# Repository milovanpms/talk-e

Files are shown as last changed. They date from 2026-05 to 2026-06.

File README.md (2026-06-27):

<p align="center">
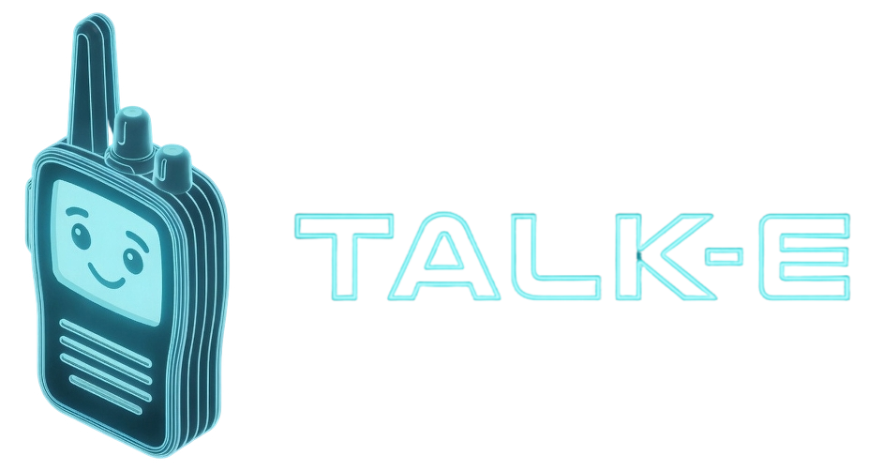
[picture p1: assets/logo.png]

</p>

<h1 align="center"></h1>

<h3 align="center">Talk-E is a walkie-talkie powered by LoRa and an ESP32-S3, operating on the 433 MHz band. And it mostly works.</h3>

<p align="center">
  
  
  
  
  
  
</p>

<h5 align="center"><a href="https://milovan.me">milovan.me</a></h5>

## In a nutshell
- **What** : Two identical devices, one button to talk, and that's it.
- **Why** : We didn't have much time, so we wanted something original, interactive, and fun to demo. The kind of project you understand immediately just by holding it in your hands.
- **Context** : Radiocommunication student project, two-person team.

## Documentation

The documentation is quite detailed, so each part has its own page instead of having it all here.

### Find your happiness:
- ⚙️ [Hardware Architecture](./docs/architecture.md): Functional synoptic diagram and component details
- 🛠️ [Firmware](./docs/firmware.md): ESP-IDF, libraries, code architecture
- 📡 [Radio Parameters](./docs/radio.md): How we use LoRa
- 🎙️ [Audio Processing](./docs/audio.md): A voice's journey through the system
- 👤 [Human-Machine Interface](./docs/hmi.md): How does it works for the user
- 🔋 [Power Supply Circuit](./docs/power.md): Power management and energy consumption
- 🔌 [Electronics](./docs/electronics.md): Prototyping, KiCad, RF design, routing rules, our conception choices
- 📐 [Mechanical Design](./docs/cad.md): Our vision of an enclosure for this device

## Repository Structure 
```
├── hardware/        # KiCad schematics, PCB
├── firmware/        # ESP-IDF code
├── docs/            # Documentation, conception notes
├── assets/          # Images, schematics and illustrations
└── case/            # 3D models
```

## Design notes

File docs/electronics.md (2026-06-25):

# 🔌 Electronics

## Prototyping

Before diving headfirst into a custom PCB, we did what every engineer on the planet would do: we grabbed a dev board off the shelf and started tinkering with it. The goal was to validate the core ideas: LoRa audio streaming, Opus encoding on an **ESP32** and the FreeRTOS task architecture.

### The development platform

The [**TTGO T-Beam V1.1**](https://github.com/lilygo/ttgo-t-beam) (by LilyGO) was our prototyping board of choice. It's a compact development board built around the original **ESP32**, featuring an **SX1276** LoRa transceiver, buttons, and a built-in **Li-Ion charging circuit** with a 18650 battery holder (even though we won't use the charging circuit).



The T-Beam already bundles almost everything the project requires on a single board: an ESP32 and a LoRa radio. This let us focus entirely on firmware during the prototyping phase without wiring up the LoRa module on our breadboard.

### What the prototyping phase validated

By the time the PCB was designed, the following had been confirmed working on the T-Beam:

- Opus encode/decode pipeline at `8 kHz`, `10 kbps`, over I2S and ADC
* LoRa TX/RX at SF7, BW 250 kHz, CR 4/5 on 433 MHz
- FreeRTOS task architecture (five concurrent tasks, dual-core assignment)
* Audio RX queue and jitter buffer
- SH1106 OLED via I2C with U8G2
* EC12 quadrature encoder decoding and PTT debouncing
- Vibration motor + FreeRTOS timer for haptic pulses
* TX/RX status LEDs

Essentially, the firmware was feature-complete before the PCB was shipped. The transition from T-Beam to custom board was mostly a matter of re-mapping GPIOs.

---

## PCB Design

With the firmware validated on the T-Beam, the next step was to translate everything into a custom PCB. The constraints were clear: fit the complete circuit onto a board small enough to live inside a handheld enclosure, while keeping the design manufacturable by a standard two-layer process and easy to solder, even with our clumsy hands.

The PCB was designed in **KiCad 10.0** and fabricated by **JLCPCB**.

> [!NOTE]
> As of writing, the PCB has not yet been soldered. Any assembly-related issues will be documented here once the board is populated and tested.

### Board overview
 
| Parameter | Value |
|---|---|
| Dimensions | `51.145 mm × 95 mm` |
| Layers | 2 (`F.Cu` + `B.Cu`) |
| Substrate | FR4 |
| Board thickness | `1.6 mm` |
| Copper thickness | `35 µm` |
| Ground planes | Both layers (poured) |
| Mounting holes | 2x M3 |

The board is rectangular and sized to fit inside a handheld enclosure with margin for mounting hardware. Two M3 mounting holes are placed at the corners.

<p align="center">
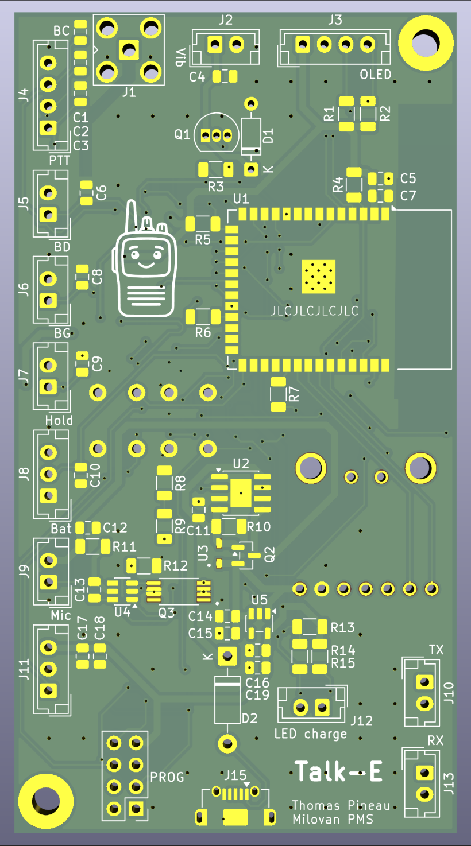
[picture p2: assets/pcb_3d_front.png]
  
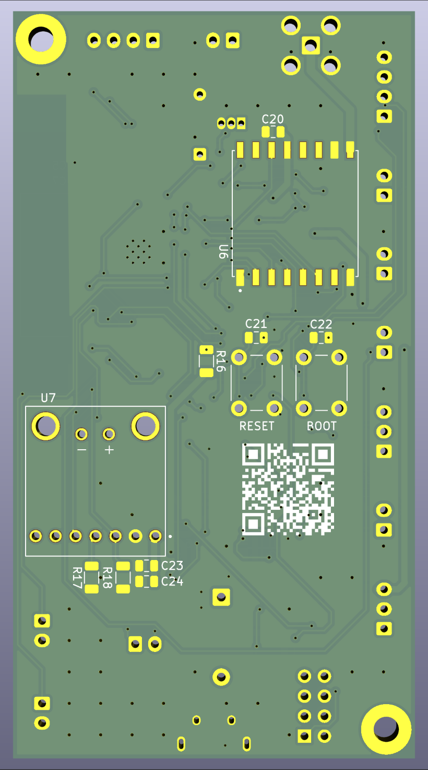
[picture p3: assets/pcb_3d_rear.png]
  
</p>

### Schematic structure

The schematic is split into two separate sheets:
 
**Sheet 1 - Power (`ihm.kicad_sch`):** Contains the complete power supply chain: Li-Ion charging (**TP4056**), battery protection (**DW01A + FS8205A**), voltage regulation (**AP2112K-3.3**), the Micro USB input connector, the SMA RF connector, the UART programming header, the BOOT and RESET buttons, and the hardware lock switch (`SW_LOCK`).
 
**Sheet 2 - Main (`talk-e.kicad_sch`):** Contains the MCU (**ESP32-S3-WROOM-1**), LoRa module (**RFM96W** based on SX1278), audio amplifier module (**MAX98357A**), microphone (**MAX4466**), rotary encoder, PTT and side buttons, OLED display, LEDs, and vibration motor, along with all their supporting passives.

<p align="center">
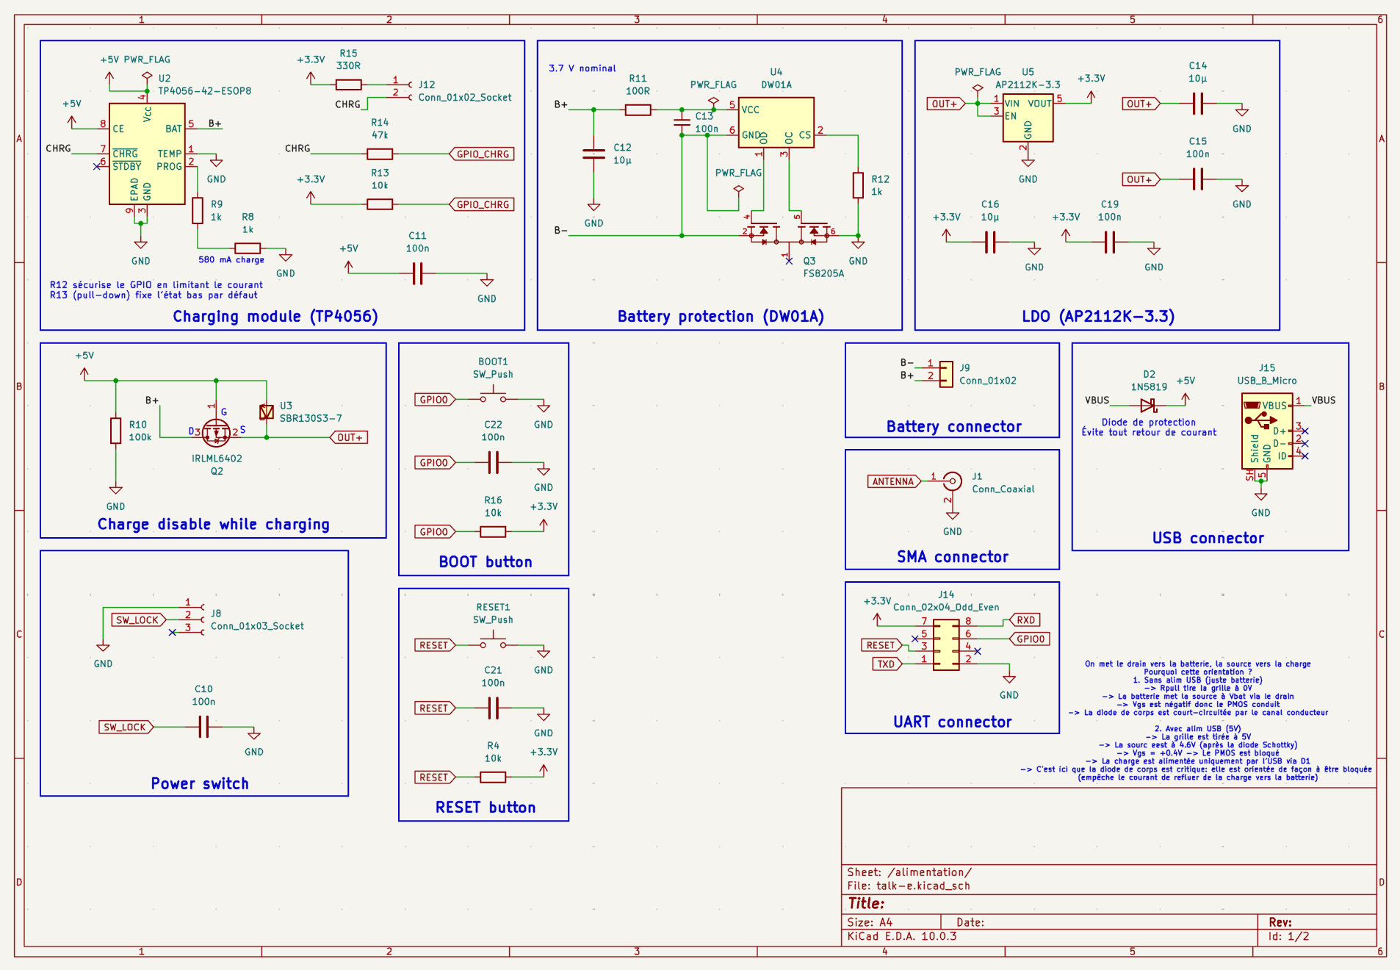
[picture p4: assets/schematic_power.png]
  
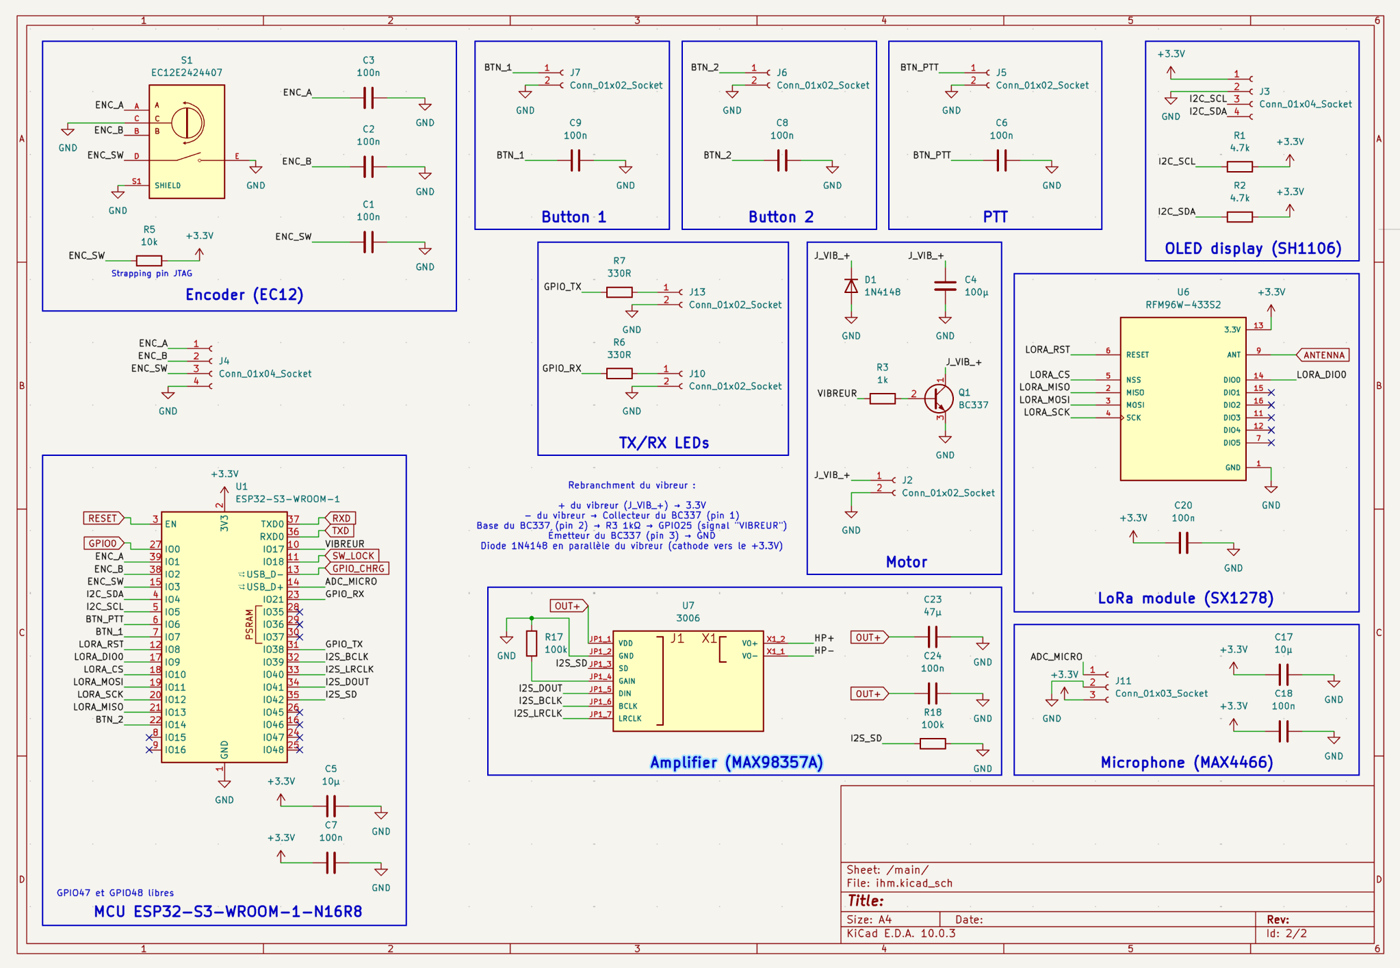
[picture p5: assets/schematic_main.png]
  
</p>

> [!NOTE]
> Yes, I know, the filenames are strange, I will update them someday.
 
Global labels tie the two sheets together for power rails (`OUT+`, `+3.3V`) and shared signals (`RESET`, `GPIO0`, `SW_LOCK`, `GPIO_CHRG`, `ANTENNA`, `RXD`, `TXD`).

### Trace widths
 
Three trace width classes are used across the board:
 
| Class | Width (mm) | Width (mil) | Used for |
|---|---|---|---|
| Power | `0.8 mm` | `31.5 mil` | All power rails (`+3.3V`, `OUT+`, `GND`, `B+`) |
| RF (microstrip) | `1.08 mm` | `42.52 mil` | SMA to SX1278 RF path |
| Signal | `0.2 mm` | `7.87 mil` | All logic signals (SPI, I2C, I2S, GPIOs) |

### RF design
 
This is probably the most layout-sensitive part of the board.
 
The **ESP32-S3-WROOM-1** module has an integrated PCB antenna, but we don't use it for LoRa. The module's antenna is only relevant if you use the ESP32's built-in Wi-Fi or Bluetooth. For LoRa, the RF signal goes through a dedicated external path.
 
The RF chain runs as follows: 

```
SMA connector (J1, Amphenol 901-143 horizontal) ➜ 50 Ω microstrip ➜ RFM96W / SX1278 (U6).
```
 
The 50 Ω microstrip was calculated using **KiCad’s built-in transmission line calculator**, using the actual stackup parameters defined in the PCB file: `1.51 mm` FR4 core with εr = `4.5`, `35 µm` copper. This yields a trace width of `1.08 mm` to match a `50 Ω` characteristic impedance.

Two ground keepout zones are placed to protect signal integrity:

- Around the microstrip trace, to exclude the ground plane and maintain the controlled impedance
* Around the **ESP32-S3** module's integrated PCB antenna, to prevent the adjacent copper from detuning it

> [!NOTE]
> Even though it is not in active use, Espressif still recommends placing a keepout zone around the integrated antenna (see [**ESP32-S3-WROOM-1** datasheet](https://documentation.espressif.com/esp32-s3-wroom-1_wroom-1u_datasheet_en.pdf)).

> ### What is a microstrip?
> A microstrip is a type of transmission line commonly used on PCBs for RF signals. It consists of a signal trace on the surface of the board, separated from the ground plane beneath it by the PCB substrate. The characteristic impedance depends on the trace width, the substrate thickness, and its dielectric constant (`εr`). Matching this impedance to `50 Ω` (the standard for RF systems) minimises reflections and ensures maximum power transfer between the SMA connector and the radio module.

### Ground planes and via stitching

Both copper layers carry a full ground pour, tied together by a dense array of vias. This was done automatically using the [**viastitching**](https://github.com/weirdgyn/viastitching) KiCad plugin, which distributes stitching vias across the board in a regular pattern.

Via stitching serves two purposes here: it lowers the ground impedance across the board (useful for the audio and power sections), and it improves RF shielding continuity around the LoRa antenna path.

### Module connectors
 
All external modules connect to the PCB via **JST EH series connectors** (2.50 mm pitch), chosen for their polarised, locking contacts — no risk of plugging something in backwards or having it vibrate loose.
 
| Connector | Pins | Module |
|---|---|---|
| `J6` | 2 | Right button |
| `J7` | 2 | Left button |
| `J9` | 2 | Battery |
| `J10` | 2 | TX LED |
| `J12` | 2 | CHRG LED |
| `J13` | 2 | RX LED |
| `J5` | 2 | PTT |
| `J2` | 2 | Vibration motor |
| `J8` | 3 | Lock switch |
| `J11` | 3 | Microphone (MAX4466) |
| `J3` | 4 | OLED display |
| `J4` | 4 | Encoder |

The **MAX98357A audio amplifier** (Adafruit breakout module, footprint `3006`) is an exception: it is soldered directly onto the PCB footprint rather than via a detachable connector, as it doesn't need a periodic replacement or disconnection.

### Power input

The board charges via **Micro USB** (`J15`, Molex 47590-0001). The USB connector feeds `VBUS` into the **TP4056** charge controller. No USB data lines are used; the connector is power-only.

A separate **UART programming header** (`PROG`, 2×4 pin header) exposes `TXD`, `RXD`, `GPIO0`, and `RESET` for flashing via a USB-to-UART adapter. The onboard `BOOT` and `RESET` push buttons allow entering the ESP32 bootloader.

### Some pictures of the board

<p align="center">
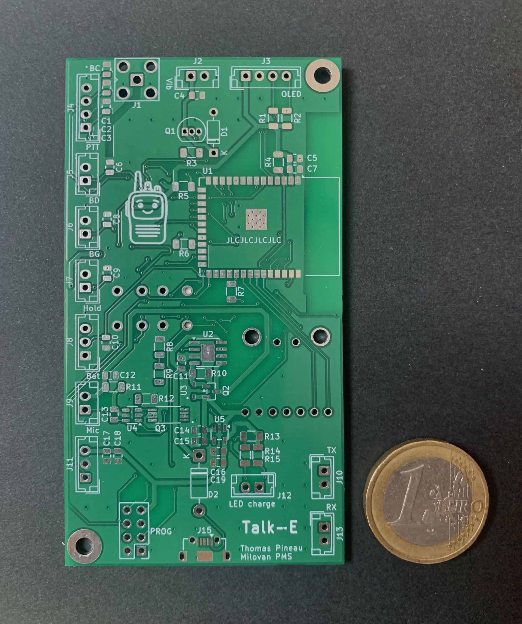
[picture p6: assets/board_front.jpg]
  
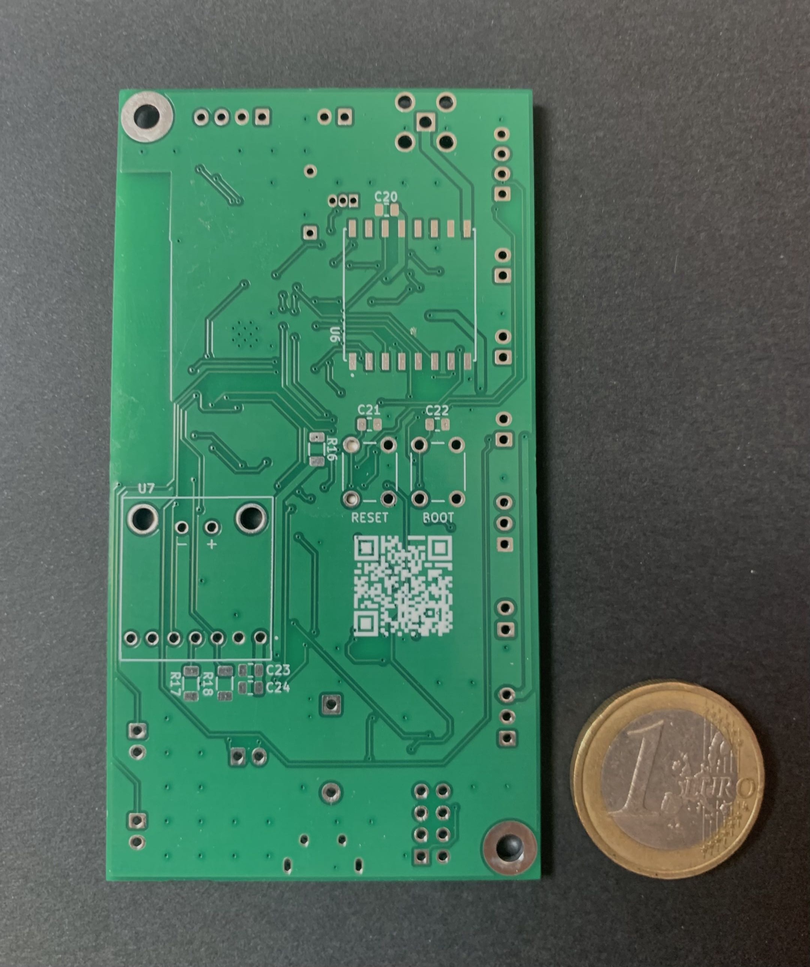
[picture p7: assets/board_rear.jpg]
  
</p>

---

## Next steps

- Assemble boards
- Validate RF performance and audio quality
- Measure real-world power consumption and autonomy

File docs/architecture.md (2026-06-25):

# ⚙️ Hardware Architecture

## Overview
The architecture is built around an **ESP32-S3** (**ESP32-S3-WROOM-1-N16R8**) that handles everything: radio via SPI, 
display via I2C, audio via I2S and GPIOs for buttons and feedback.

### Why specifically the S3?
We picked an **S3** module for its built-in PSRAM, which we needed for audio buffering. See the corresponding section on audio processing.

### Why did you choose the module with the integrated antenna?
We took the **ESP32-S3-WROOM-1** (integrated PCB antenna) instead of the **ESP32-S3-WROOM-1U**, even though we don't need the built-in `2.4 GHz` antenna. The main reason was that we already had several **ESP32-S3-WROOM-1** modules available on campus; but it would also work with the module without an antenna!

## Functional block diagram
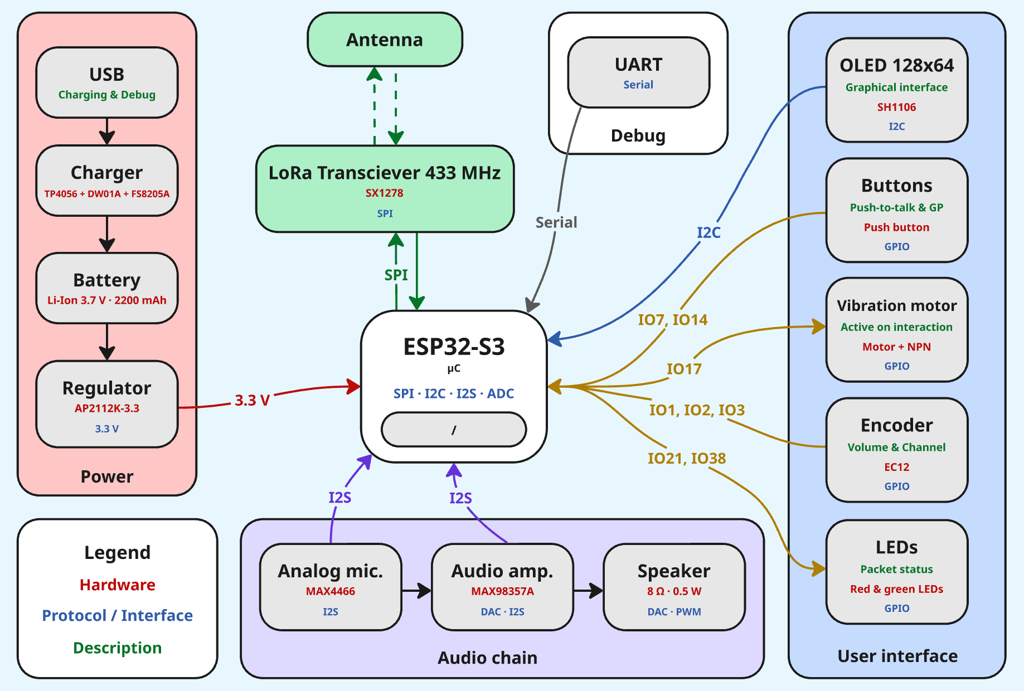
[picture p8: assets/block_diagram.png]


## Component Details

| Block | Component | Role |
|---|---|---|
| Microcontroller | **ESP32-S3** | Main processing, SPI/I2C/I2S |
| Radio | **SX1278** | LoRa transceiver, `433 MHz` |
| Audio input | **MAX4466** | Analog microphone |
| Audio output | **MAX98357A** | Class D amplifier |
| Display | **SH1106 OLED 128x64** | Status display |
| Battery | **Li-Ion 3.7V 2000mAh** | Power source |
| Charging | **TP4056** | Charge controller |
| Protection | **DW01A + FS8205A** | Overvoltage, overdischarge, short-circuit |
| Regulation | **AP2112K-3.3** | `3.3 V` |
| Vibration | Vibration motor | Haptic feedback |

## Pin Mapping

As you can see, the GPIOs are nearly fully used!

| Component | Pin | ESP32-S3 GPIO | Interface |
|---|---|---|---|
| **SX1278** | `MOSI` | `GPIO11` | SPI |
| **SX1278** | `MISO` | `GPIO13` | SPI |
| **SX1278** | `CS` | `GPIO10` | SPI |
| **SX1278** | `DIO0` | `GPIO9` | SPI |
| **SX1278** | `RST` | `GPIO8` | SPI |
| **SX1278** | `SCK` | `GPIO12` | SPI |
| **SH1106** | `SDA` | `GPIO4` | I2C |
| **SH1106** | `SCL` | `GPIO5` | I2C |
| **MAX98357A** | `BCLK` | `GPIO39` | I2S |
| **MAX98357A** | `LRCLK` | `GPIO40` | I2S |
| **MAX98357A** | `DOUT` | `GPIO41` | I2S |
| **MAX98357A** | `SD` | `GPIO42` | I2S |
| **MAX4466** | - | `GPIO14` | ADC |
| **Encoder** | `A` | `GPIO1` | GPIO |
| **Encoder** | `B` | `GPIO2` | GPIO |
| **Encoder** | `SW` | `GPIO3` | GPIO |
| **PTT button**  | - | `GPIO6` | GPIO |
| **Button 1** | - | `GPIO7` | GPIO |
| **Button 2** | - | `GPIO14` | GPIO |
| **Vibration motor** | - | `GPIO17` | GPIO |
| **Lock switch** | - | `GPIO18` | GPIO |
| **TX LED** | - | `GPIO38` | GPIO |
| **RX LED** | - | `GPIO21` | GPIO |
| **CHRG LED** | - | `GPIO13` | GPIO |
| **RESET button**| `EN` | - | GPIO |
| **BOOT button** | - | `GPIO0` | GPIO |

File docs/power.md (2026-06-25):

# 🔋 Power Supply Circuit

Designing a power supply circuit is a crucial step when you create a device. Especially portable ones: you have to think about the global consumption of the device, which battery suits the best for a *not-ridiculous* autonomy, how to charge it and how to protect the circuit; **to make sound, not smoke**.

## A little block diagram

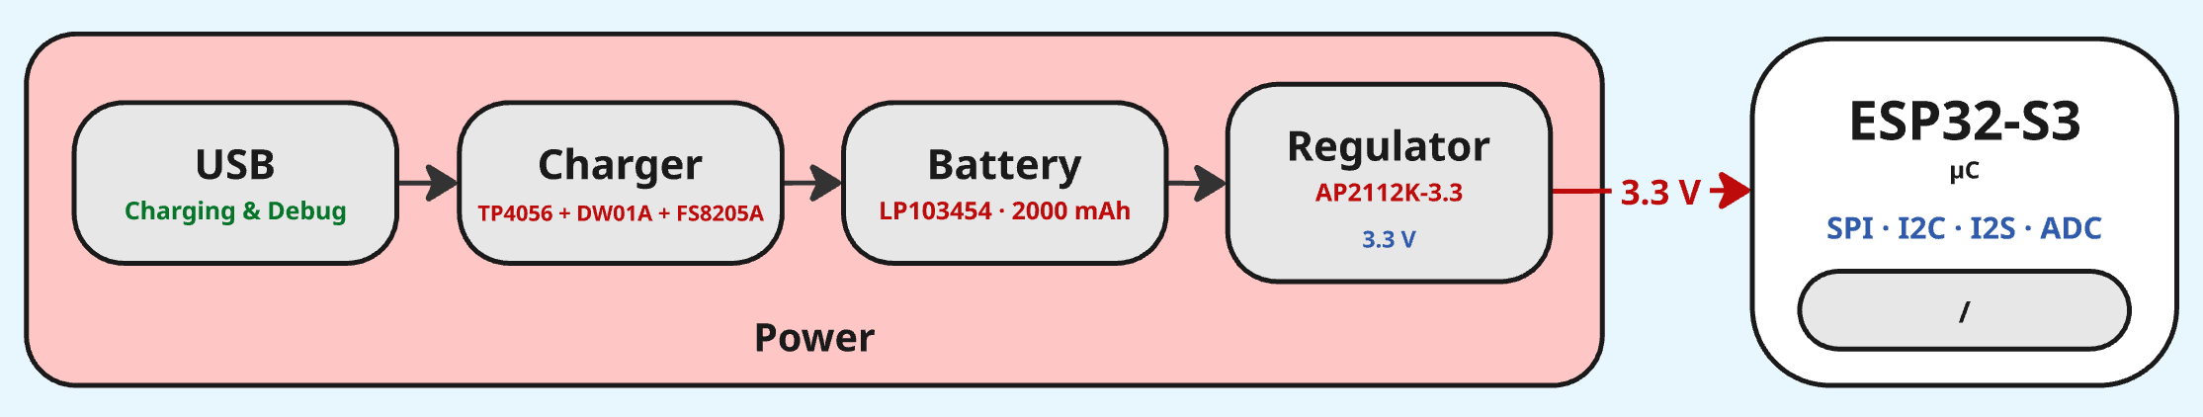
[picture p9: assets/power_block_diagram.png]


## Power Consumption

This estimate was done early in the design process to size the LDO regulator correctly. The audio amp (**MAX98357A**) is fed directly from the battery output rather than through the **AP2112K**, which would never survive a `500 mA` peak on top of everything else.

| Component | Typical current |
|---|---|
| **ESP32-S3** | `~240 mA peak`; `~80 mA average` |
| **SX1278** | `~120 mA (TX)` |
| **SH1106** | `~20 mA` |
| Vibration motor | `~100 mA peak`; `~60 - 80 mA average` |
| LEDs | `~20 mA` |
| Audio amp | `~500 mA peak`; not connected on regulator |
| Buttons | `~0 mA` |
| Switch | `~0 mA` |
| **Total peak** | `~500 mA` (excluding audio amp) |
| **Total peak** | `~1000 mA` (including audio amp) |

## Voltage Regulation (AP2112K-3.3)

The **AP2112K-3.3** is a low-dropout linear regulator that converts the battery voltage down to a stable `3.3 V` for the logic side of the circuit. It has a dropout voltage of `~300 mV`, which means it needs at least `3.6 V` on its input to guarantee a stable `3.3 V` output. The audio amp (**MAX98357A**) bypasses it entirely and runs directly off the battery output, keeping the LDO within its limits. It can also provide up to `600 mA`, which is perfect for our application.

## Charging Circuit (TP4056)

The **TP4056** is a single-cell Li-Ion charge controller. It handles the full charging 
cycle and signals its state via the `CHRG` pin.
We configured the charge current to `580 mA` via `RPROG` (`R8`); other values are available in the 
datasheet.
There is also a `STDBY` pin, used to get the charge termination status. We won't use it in this project.

| Terminal | Output | Voltage | Usage |
|---|---|---|---|
| `B+` / `B-` | Raw battery voltage | `3.7 V` | Physical battery connection |
| `OUT+` / `OUT-` | Protected battery voltage | `3.7 V` | Rest of the circuit |

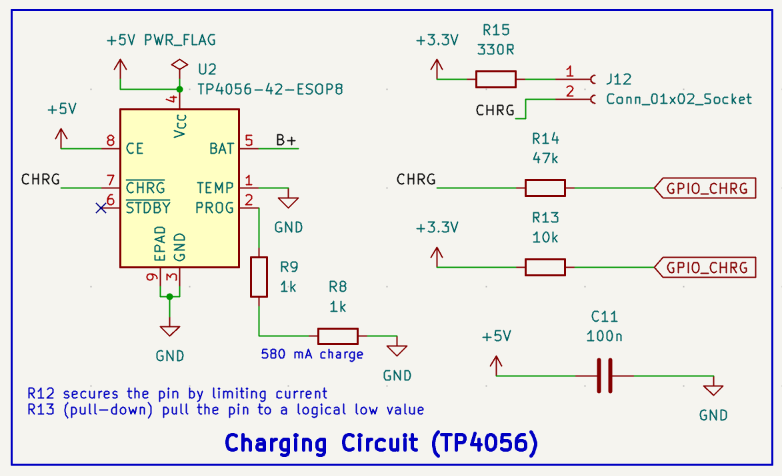
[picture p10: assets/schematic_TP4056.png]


## Battery Protection (**DW01A** + **FS8205A**)

The **DW01A** is a Li-Ion protection IC. It monitors the battery and cuts 
the circuit in three situations:

| Fault | Threshold | Action |
|---|---|---|
| Overcharge (OC) | `> 4.25 V` | Cuts charge MOSFET |
| Overdischarge (OD) | `< 2.5 – 2.7 V` | Cuts discharge MOSFET |
| Overcurrent / short | Current spike | Cuts immediately |

The **DW01A** doesn't cut current directly; it drives the **FS8205A**, a dual back-to-back 
MOSFET in a single package. Two MOSFETs are needed because a single one can't block 
current in both directions due to its body diode.

One more thing to keep in mind: the **AP2112K** LDO drops out at `VIN < 3.6 V`, while the 
**DW01A** only cuts at `~2.6 V`. There's a grey zone between `~3.0 V` and `~3.6 V` where the 
battery is still connected but the `3.3 V` rail is no longer guaranteed; the firmware 
should monitor battery voltage via ADC and warn the user before reaching this zone. (todo!)

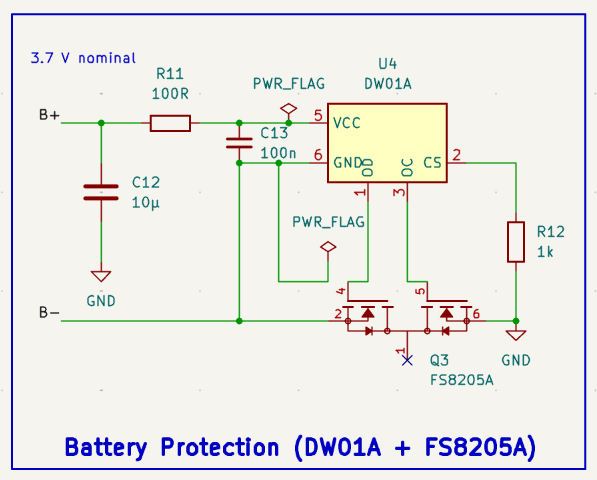
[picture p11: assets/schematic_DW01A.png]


## Charge Indicator

The **TP4056** exposes a `CHRG` open-drain pin that reflects the charging state. We use it 
both for a visual LED indicator and for a GPIO read by the **ESP32-S3** to show it on the screen.

| State | CHRG pin | LED | **ESP32-S3** reads |
|---|---|---|---|
| Charging | LOW (active) | ON | `LOW` |
| Charge complete | Floating (pull-up) | OFF | `HIGH` |
| No battery / error | Blinking | Blinking | Alternating |

The GPIO is pulled up to `3.3 V` via `10 kΩ` when `CHRG` is floating, and pulled to `GND` via 
`47 kΩ` when active. The **ESP32-S3** displays the corresponding icon on the OLED display.

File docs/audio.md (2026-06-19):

# 🎙️ Audio Processing

## A voice's journey through the system

The audio pipeline handles everything between the microphone and the antenna on one side, and between the antenna and the speaker on the other. Everything runs at `8 kHz`, which is telephony-grade quality; not a hi-fi *Pro Max Plus* sound, but *theoretically* perfectly intelligible for a walkie-talkie.

The pipeline splits into two independent paths:

**TX Path (transmit):**
```
MAX4466 ➜ ADC @ 40 kHz ➜ DC-block ➜ Decimation /5 ➜ AGC ➜ PCM (16-bit @ 8 kHz) ➜ Opus encode ➜ LoRa TX
```

**RX Path (receive):**
```
LoRa RX ➜ audio_rx_queue ➜ Opus decode ➜ Volume gain ➜ Jitter buffer ➜ I2S ➜ MAX98357A
```

Both paths run as separate FreeRTOS tasks (`audio_tx_task` and `audio_rx_task`) and communicate with the radio layer through a shared queue (`audio_rx_queue`).

> ### What is PCM?
> PCM (Pulse Code Modulation) is the standard way of representing analog audio as digital data. Each audio sample is stored as a numerical value corresponding to the instantaneous amplitude of the sound wave.
>
> In our system, the microphone signal is converted into 16-bit signed PCM samples at `8 kHz`, meaning:
> - 8,000 samples per second are taken;
> * Each sample is represented by a 16-bit integer (`-32,768` to `32,767`);
> - And these raw samples are then passed to the Opus encoder for compression.

## Audio Acquisition

### The Microphone: MAX4466

The **MAX4466** is an analog electret microphone amplifier. It outputs an analog voltage that varies with the sound pressure level. This analog signal is read by **ESP32-S3**'s internal ADC.

### ADC Configuration

Rather than sampling the microphone at the final `8 kHz` target rate, we run the ADC at `40 kHz` and then decimate. This approach is less sensitive to aliasing and fits naturally with the ESP-IDF continuous ADC driver, which is more reliable at higher rates.

| Parameter | Value |
|---|---|
| ADC unit | `ADC1` |
| Channel | `ADC1_CH0` (GPIO36) |
| Bit width | `12 bits` (values from 0 to 4095) |
| Attenuation | `12 dB` (allows reading voltages up to ~3.1 V) |
| Sample rate | `40,000 Hz` |
| Samples per DMA read | `256` |

> #### Why the hell did you take an analog microphone module?
> Because that's what we had in the parts bin.
> 
> More seriously, the MAX4466 was simply the microphone module we already had available on campus when the project started. On top of that, it could be connected directly to the **ESP32-S3**'s internal ADC with minimal effort.
>
> Looking back, we probably underestimated the impact of the microphone choice on the overall audio chain. We did not spend much time evaluating microphone options early in the project and only later realised how significant the difference between a basic analog module and a modern digital microphone could be.
>
> If we were to redesign the system today, we would seriously consider using a digital I2S microphone instead. Besides simplifying the acquisition stage, it would likely provide cleaner audio and avoid some of the limitations and noise introduced by the **ESP32**'s internal ADC.

The ADC runs in **continuous mode with DMA** (Direct Memory Access). DMA is a hardware mechanism that copies data from the ADC directly into a memory buffer without involving the CPU; this means the processor doesn't waste cycles waiting for each individual sample, and can do other things while the ADC fills the buffer in the background.

### Decimation /5 (40 kHz ➜ 8 kHz)

> ### What is decimation?
> It's a signal processing technique that reduces the sampling rate of a digital signal. Instead of keeping every sample, we group them and compute an average, which produces fewer samples per second.

We accumulate 5 consecutive ADC samples and average them into a single output sample. This divides the effective sample rate by 5: `40 kHz ÷ 5 = 8 kHz`. The result is a standard telephony sample rate, well supported by Opus.

## Signal Pre-Processing

Before the PCM samples reach the Opus encoder, two processing steps clean up the signal.

### DC-Block Filter

The **MAX4466** output sits around a DC bias point rather than around zero. If left uncorrected, this constant offset would be interpreted as a very low-frequency audio signal and would waste bitrate in the encoder.

A simple IIR high-pass filter removes this offset:

```c
dc_blocked = raw - prev_raw + 0.995f * prev_dc;
```

> ### How does the filter work?
> It's a first-order high-pass filter. It lets audio frequencies pass through while blocking the constant DC component. The coefficient `0.995` controls how aggressively low frequencies are attenuated; values close to `1.0` give a very low cutoff frequency, which is what we want (we only want to remove DC, not attenuate speech).

### Automatic Gain Control (AGC)

Speech level varies a lot; someone whispering vs. shouting at the microphone produces signals of very different amplitudes. Without gain control, quiet speech would be barely audible after transmission, while loud speech would saturate.

The AGC dynamically adjusts a gain multiplier:

| Parameter | Value | Role |
|---|---|---|
| Fixed pre-gain | `×28.0` | Scales the 12-bit ADC range to 16-bit PCM range |
| Threshold | `16,000` (out of 32 767) | Above this, gain is reduced to prevent clipping |
| Attack | `0.05` | How quickly gain decreases when signal is too loud |
| Release | `0.005` | How slowly gain recovers when signal calms down |

The asymmetry between attack and release is intentional: gain is reduced quickly to avoid clipping, but recovered slowly to avoid pumping artefacts.

## Compression with Opus

### What is Opus?

**Opus** is an open audio codec developed by the IETF, widely used for real-time voice and audio communications (WebRTC, Discord, VoIP systems). It supports bitrates from `6 kbit/s` to `510 kbit/s` and is quite efficient at low bitrates for speech. 

### Why Opus and not something else?

Opus offers better quality at lower bitrates than other speech codecs (like **G.711**, **G.726** or **G.729**), is actively maintained, has a clean C API, and has an official ESP-IDF component available. It was the obvious choice.

### Encoder configuration

The PCM frames produced by the acquisition pipeline are fed into the Opus encoder 80 samples at a time.

> ### What is a frame?
> Opus, like most audio codecs, doesn't process one sample at a time. It processes a fixed-size block of samples (a "frame") and outputs a compressed packet. This block size directly controls latency.

We settled these settings for the encoder:

| Parameter | Value | Explanation |
|---|---|---|
| Sample rate | `8 000 Hz` | Telephony grade, sufficient for speech |
| Channels | `1` (mono) | We only have one microphone |
| Application | `VOIP` / `RESTRICTED_LOWDELAY` | Optimised for real-time voice, minimal buffering |
| Bitrate | `10,000 bit/s` | Fits comfortably within the LoRa `~10.9 kbit/s` budget |
| Complexity | `1` (out of 10) | Minimum CPU cost — the ESP32-S3 has other tasks to run |
| Signal type | `OPUS_SIGNAL_VOICE` | Tells the encoder to use voice-optimised coding decisions |
| Bandwidth | `NARROWBAND` (0 – 4 kHz) | Telephony bandwidth — further reduces encoded size |
| Frame size | `80 samples` | 80 samples @ 8 kHz = **10 ms per frame** |

With these settings, each Opus packet is typically a few tens of bytes, well within the **240 byte** SX1278 payload limit defined in `lora_app.h`.

### Latency budget

The 10 ms frame size means the encoder introduces a minimum of 10 ms of algorithmic latency per direction. In practice, the total one-way latency also includes LoRa airtime, the jitter buffer on the receiver side (40 ms, see below), and FreeRTOS scheduling. The overall latency is acceptable for a push-to-talk device; it's not a phone call, and users naturally wait for the other person to finish before replying.

> ### Approximate one-way latency
> - **Opus frame accumulation:** 10 ms
> - **LoRa airtime:** Typically a few tens of milliseconds
> - **Jitter buffer:** 40 ms
>
> **Total:** ~70 ms

## Memory: PSRAM and the role of the ESP32-S3

> ### What is PSRAM?
> PSRAM (Pseudo-Static RAM) is additional RAM connected to the microcontroller via the SPI bus. On the **ESP32-S3-WROOM-1-N16R8**, this is an external 8 MB chip soldered on the module itself. It's slower than internal RAM but vastly larger; the internal RAM of the **S3** is only a few hundred kilobytes.

The Opus codec requires a significant amount of memory for its internal state, lookup tables, and processing stack. On most embedded systems, this is a problem. Here, we offload it to PSRAM via ESP-IDF's menuconfig:

- **SPI RAM support** is enabled under `Component config → ESP PSRAM`.
* The access method is set so that PSRAM is available both via standard `malloc()` and via `heap_caps_malloc(..., MALLOC_CAP_SPIRAM)`.
- Under `Component config ➜ Opus Audio Codec`, the **memory preference** is set to *"Prefer PSRAM, fallback to internal RAM"*, which causes the Opus encoder and decoder state to be allocated in PSRAM automatically.

The ADC DMA buffers, by contrast, **must** stay in internal RAM. DMA controllers on the **ESP32-S3** cannot address PSRAM directly, which is why `audio_tx_task` allocates its ADC buffer with `MALLOC_CAP_DMA | MALLOC_CAP_INTERNAL`.

This is the primary reason we chose the **S3** variant specifically: it's a common ESP32 module with integrated PSRAM, and without it, the Opus encoder simply would not fit in memory alongside the rest of the firmware.

## Reception Path

### Queue between tasks

The `task_lora` task receives raw LoRa packets and pushes them into `audio_rx_queue`, a FreeRTOS queue of 32 slots, each holding a complete `audio_pkt_t` (data buffer + actual length). The `audio_rx_task` reads from this queue and handles decoding.

If the queue fills up (e.g. the decoder is temporarily slow), incoming packets are silently dropped; this is intentional. Dropping a packet causes a brief audio gap, which is far preferable to blocking `task_lora` and causing it to miss subsequent LoRa frames entirely.

### Opus decoding

Each packet received from the queue is decoded by a global `OpusDecoder` instance (created once at startup) back into 80 PCM samples at `8 kHz`.

### Volume control

After decoding, a linear gain is applied to every sample before playback:

```c
float vol_gain = (volume / 100.0f) * 2.0f;  // 0 to 200%
```

The `volume` variable (0-100) is controlled by the rotary encoder on the device. The gain range of `0x` to `2x` allows the user to amplify the decoded signal up to twice its original level, useful in noisy environments.

Samples are clamped to the 16-bit signed range (`−32,768` to `32,767`) after gain is applied to prevent saturating artefacts.

### Jitter buffer

> ### What is jitter?
> In a radio link, consecutive packets don't always arrive with perfectly regular spacing. Some arrive a few milliseconds early, others late, due to radio channel variations and scheduling. This irregular timing is called jitter.

A jitter buffer absorbs this variability by storing a few decoded frames before they are played, and reading them out at a steady rate. Ours holds 4 frames:

| Parameter | Value |
|---|---|
| Buffer depth | `4 frames` |
| Frame duration | `10 ms` |
| Total buffering | `40 ms` |

This 40 ms window is the maximum jitter the system can absorb without audible gaps. It also adds 40 ms of latency on the receive side; a reasonable trade-off for a walkie-talkie.

If the buffer is empty (no packets received), the task simply waits without writing anything to I2S, which causes the **MAX98357A** to output silence. This is also what happens when corrupted packets are discarded by the **SX1278** CRC checker (see [radio documentation](./radio.md)).

### I2S output to MAX98357A

> ### What is I2S?
> I2S (Inter-IC Sound) is a digital communication protocol specifically designed for transporting audio data between integrated circuits. Unlike analog audio signals, I2S transmits audio as a stream of digital samples synchronised by dedicated clock signals.
>
> In our system, the ESP32-S3 sends the decoded PCM samples to the **MAX98357A** amplifier over I2S. The amplifier receives the digital audio stream, converts it internally to an analog signal, and drives the speaker.
>
> Using I2S avoids the noise and quality issues associated with transmitting low-level analog audio signals across the PCB.

> [!NOTE]
> Although I2S supports stereo audio, our implementation only uses a single mono channel.

The decoded and volume-adjusted PCM samples are written to the **MAX98357A** amplifier via I2S:

| Parameter | Value |
|---|---|
| I2S peripheral | `I2S_NUM_1` |
| Sample rate | `8 000 Hz` |
| Bit depth | `16 bits` |
| Mode | Mono, Philips standard |
| DMA descriptors | `8` |
| DMA frame size | `256 samples` |

## Known Limitations

**Audio quality** is telephony-grade. The combination of 8 kHz bandwidth, Opus narrowband mode, and 10 kbps bitrate produces intelligible but not crystal-clear speech. This was a trade-off to stay within the LoRa throughput budget.

**Encoder complexity is at minimum.** Setting `OPUS_SET_COMPLEXITY(1)` keeps CPU usage low but produces slightly less efficient compression than higher complexity levels. At `10 kbps` over a narrowband signal this might not be noticeable in practice.

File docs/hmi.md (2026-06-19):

# 👤 Human-Machine Interface

From the beginning, we wanted Talk-E to feel like a finished product; not a dev board with DuPont wires *hanging out like cobwebs*. The kind of device you pick up, understand in ten seconds, and use without using a manual.

The interface is **deliberately minimal**: one rotary encoder, one PTT button, one channel button, one lock switch, and a small OLED display. No touchscreen, no menu tree to navigate, no deep configuration. Every interaction has immediate physical and visual feedback: the encoder clicks at each detent, the motor confirms your input, the display reacts instantly.

## Rotary Encoder (EC12)

The encoder has three electrical signals: **A**, **B**, and **SW** (push button used as PTT).

### Quadrature decoding

A rotary encoder outputs two square waves (A and B) that are 90° out of phase. The direction of rotation depends on which signal leads the other.

Rather than using interrupts, we decode the encoder by polling every 5 ms. This avoids the false transitions caused by contact bounce; a common issue with mechanical encoders. Hardware-side, 100 nF capacitors between A/GND and B/GND filter out electrical noise.

Each polling cycle, A and B are read as 2-bit state (`00`, `01`, `10`, or `11`). Combining the previous state with the current state gives a 4-bit index into a lookup table:

```c
static const int8_t quad_table[16] = {
         0,  -1,  1,  0,   /* prev = 00 */
         1,   0,  0, -1,   /* prev = 01 */
        -1,   0,  0,  1,   /* prev = 10 */
         0,   1, -1,  0    /* prev = 11 */
};
```

Each valid transition returns `+1` (clockwise) or `-1` (counter-clockwise). Invalid transitions (caused by noise or missed edges) return `0` and are ignored.

Because the EC12 has **4 quadrature transitions per mechanical detent**, transitions are accumulated in a counter. Only when the accumulator reaches ±4 is a single click credited and a vibration pulse fired. This prevents accidental double-counts on a single detent.

### Volume and channel modes

The encoder operates in two modes:

| Mode | Encoder action | Effect |
|---|---|---|
| `MODE_VOLUME` | Rotate | Adjust volume (0 to 100, step 5) |
| `MODE_CHANNEL` | Rotate | Cycle through 8 channels (wrap-around) |

Pressing the **channel button** (GPIO38, separate from the encoder push) toggles between the two modes.

Both modes have an inactivity timeout after which the display returns to its idle mode:

| Mode | Timeout | Behaviour |
|---|---|---|
| `MODE_VOLUME` | 1.6 s | Volume bar is hidden after 1.6 s without rotation |
| `MODE_CHANNEL` | 3 s | Returns to `MODE_VOLUME` after 3 s without rotation |

The timer resets on every encoder interaction, ensuring it only triggers after genuine inactivity.

### Push-to-Talk (PTT)

The PTT function is mapped to the encoder's push button (**SW**, GPIO2).

Debouncing is done in software by counting how many consecutive 5 ms polls agree on the button state. A press is registered only after **10 consecutive stable low readings** (50 ms of stable signal).

- **Press detected:** calls `lora_start_tx()` ➜ radio switches to TX, LED lights up.
- **Release detected:** calls `lora_stop_tx()` ➜ radio returns to IDLE, reception re-armed.

The PTT is fully disabled when the lock switch is active.

### Channel Button

A dedicated push button (GPIO38) handles mode switching. It uses the same software debouncing approach as the PTT: 50 ms stability threshold, 5 ms polling.

Only falling edges (button press, not release) are registered.

### Lock Switch

A physical slide switch (GPIO15, active low) locks the device controls.

When active, `task_encodeur` skips all encoder decoding, PTT detection, and channel button polling. The display shows a stop sign icon. This prevents accidental channel changes or transmissions when the device is pocketed.

### Channel Map

8 channels are defined, covering the 433 MHz and adjacent bands:

| Channel | Frequency |
|---|---|
| CH1 | 433.050 MHz |
| CH2 | 434.100 MHz |
| CH3 | 434.700 MHz |
| CH4 | 435.300 MHz |
| CH5 | 435.900 MHz |
| CH6 | 436.500 MHz |
| CH7 | 437.100 MHz |
| CH8 | 437.700 MHz |

Channels 4 through 8 fall outside the European LPD band (`433.05–434.79 MHz`). They are available for ~~fun~~ laboratory testing.

When the user selects a new channel in `MODE_CHANNEL`, `channel_apply_frequency()` immediately calls `lora_set_frequency()` to update the SX1278, provided the radio is in `RADIO_IDLE` state.

---

## Display

The **SH1106** OLED (`128x64` pixels) is driven by the [**U8G2**](https://github.com/olikraus/u8g2) library.

`task_display` refreshes the screen every 20 ms (up to 50 FPS). Each cycle, it reads the current encoder values, checks the radio state, and redraws the full frame buffer before calling `u8g2_SendBuffer()`.

### Volume mode (default)

The main screen, active most of the time:

- **Top bar:** channel icon (Siji font), stop sign icon if locked, signal strength icon, battery icon.
- **Center:** status text in `doomalpha04` font.
  - `"Disponible"` when idle.
  - `"Transmission..."` when transmitting, with animated dots cycling through `""` → `"."` → `".."` → `"..."` every 250 ms.
  - `"Acquisition..."` when receiving, same animation.
- **Bottom:** rounded volume bar with a matching icon (muted / low / medium / high), visible for 1.6 s after the last volume interaction.

The volume bar is drawn by a custom function (`drawRoundedVolumeBar()`) that handles both the fill level and the rounded end caps using U8G2 circle and rectangle primitives.

### Channel mode

Shown when the user switches to `MODE_CHANNEL`:

- **Center:** channel icon rendered at ×2 size.
- **Below:** the channel frequency in `bpixeldouble` font.
- **Bottom:** `"Choix du canal"` subtitle.

Automatically reverts to volume mode after 3 s of inactivity.

---

## Feedback

### LEDs

Two indicator LEDs signal the radio state:

| LED | GPIO | State |
|-----|---|---|
| TX | `GPIO0` | ON while transmitting |
| RX | `GPIO4` | ON during an active reception session |

Both are off in `RADIO_IDLE`. They are driven directly by `lora_led_tx()` and `lora_led_rx()` called from `lora_app.c` on state transitions.

### Vibration Motor

The vibration motor provides haptic confirmation of user interactions. It fires a **50 ms pulse** in two situations:

- Each encoder detent (clockwise or counter-clockwise).
- PTT button press.

The pulse is implemented with a non-blocking FreeRTOS timer: `vib_pulse()` switches the GPIO high and resets the timer; the timer callback switches it low 50 ms later. This means the encoder task is never blocked waiting for the motor to finish.

If multiple pulses are requested within 50 ms (fast rotation), the timer is simply reset each time, extending the motor-on time slightly rather than queuing up separate pulses.

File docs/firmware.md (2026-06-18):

# 🛠️ Firmware

## Overview

The firmware is built on **ESP-IDF** (Espressif IoT Development Framework) and uses **FreeRTOS** as its real-time operating system.

> ### What is FreeRTOS?
> FreeRTOS is a lightweight real-time operating system designed for microcontrollers. It lets you run multiple independent tasks concurrently, each with its own stack, priority, and scheduling behaviour. On the **ESP32-S3**, FreeRTOS runs on both cores simultaneously, which means two tasks can execute in parallel.

The firmware is split into five independent tasks that communicate through shared variables and FreeRTOS queues.

## Task Architecture

### Task table

| Name | Function | Core | Priority | Stack | Role |
|---|---|:----:|:---:|---:|---|
| `enc` | `task_encodeur` | 1 | 5 | 4,096 B | Encoder polling, PTT, channel button |
| `task_lora` | `task_lora` | * | 4 | 2,048 B | LoRa RX/TX state machine |
| `audio_rx` | `audio_rx_task` | 0 | 5 | 8,192 B | Opus decode ➜ jitter buffer ➜ I2S |
| `disp` | `task_display` | 0 | 3 | 4,096 B | OLED display refresh |
| `audio_tx` | `audio_tx_task` | 0 | 3 | 16,384 B | ADC acquire ➜ Opus encode ➜ LoRa TX |

Regarding priorities and core assignments, we tried multiple configurations and we found this one to be the most stable.

### Dual-core assignment

`task_encodeur` runs exclusively on **Core 1**. All other tasks run on **Core 0**.

This isolation is intentional. The encoder task runs at 5 ms intervals and must stay responsive at all times for accurate quadrature decoding and PTT detection. Pinning it to **Core 1** means it is never preempted by the audio or display tasks running on **Core 0**, which is especially important given that `audio_tx_task` has a large 16 KB stack and does Opus compression work.

### Inter-task communication

| Producer | Consumer | Mechanism | Purpose |
|---|---|---|---|
| `task_lora` | `audio_rx_task` | `audio_rx_queue` (32 slots) | Pass received LoRa packets to the decoder |
| `task_encodeur` | `task_lora` | `radio_state` (volatile + mutex) | Signal TX start/stop via PTT |
| `task_encodeur` | `task_display` | `volume`, `channel`, `current_mode` (volatile) | Drive display updates |
| `task_lora` | `task_display` | `radio_state` (volatile, read-only) | Show IDLE / TX / RX status |

`radio_state` is written through a `RADIO_STATE_SET()` macro that takes a mutex, since both `task_encodeur` (writes `RADIO_TX`) and `task_lora` (writes `RADIO_RX` / `RADIO_IDLE`) can update it concurrently.

> ### What is a mutex?
> A mutex (mutual exclusion) is a synchronization mechanism used to protect shared resources from being accessed by multiple tasks at the same time. In FreeRTOS, a mutex ensures that only one task can access a critical section of code or a shared peripheral (such as UART, SPI, or I2C) at any given moment. If another task tries to acquire the mutex while it is already locked, it will be blocked until the mutex is released.

## Initialisation Sequence

Everything starts in `app_main()`. The initialisation order matters: peripherals must be ready before the tasks that use them are created.

**1. I2C bus:** The display communicates via I2C. The bus is created first since the [**U8G2**](https://github.com/olikraus/u8g2) library needs it immediately during display init.

**2. SH1106 display:** **U8G2** is initialized with the custom I2C callbacks, the display is powered on and cleared.

**3. EC12 encoder GPIOs:** Pins A, B, and SW configured as inputs with pull-ups.

**4. Channel button GPIO:** Dedicated button for mode switching.

**5. Vibration motor + timer:** GPIO output configured, 50 ms FreeRTOS timer created, motor forced off.

**6. LoRa LEDs:** TX and RX indicator GPIO outputs initialized and switched off.

**7. LoRa module:** `lora_init()` followed by the full RF configuration (explicit header mode, 10 dBm, 250 kHz, 433 MHz, SF7, CR 4/5, CRC enabled). The module is fully configured before any LoRa task starts.

**8. Core task creation:** `task_encodeur` (Core 1), `task_display` (Core 0), `task_lora` (any core). The LoRa application layer (`lora_app_init`) is called from inside `task_lora` on first run.

**9. I2S peripheral init:** Audio output configured for the **MAX98357A** amplifier.

**10. ADC peripheral init:** Continuous ADC driver started for the **MAX4466**.

**11. Audio task creation:** `audio_tx_task` and `audio_rx_task` created last, once the peripherals they depend on are ready.

## Watchdog

`task_encodeur` registers itself with the ESP-IDF task watchdog (`esp_task_wdt_add`) and calls `esp_task_wdt_reset()` at every polling cycle. If the task ever hangs, the watchdog will trigger a system reset. Given that this task also handles the PTT, a lockup here would leave the radio stuck in TX, which is exactly the kind of failure the watchdog is there to catch.

## Human-Machine Interface

See [HMI documentation](./hmi.md).

## Known Limitations

**`display_settings.c` is a stub.** The settings menu exists as a function that only draws a border frame (currently).

**Channel change is rejected during RX.** If the user tries to change channel while receiving a message, the change is dropped. There is currently no visual feedback to indicate this to the user.

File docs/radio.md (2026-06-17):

# 📡 Radio Parameters

## Why LoRa and why 433 MHz

Several wireless technologies were considered during the design phase. Traditional modulation schemes such as FSK can provide higher data rates, while technologies like Wi-Fi or Bluetooth offer much greater throughput. However, our primary objective was not audio quality but communication range, robustness, and low hardware complexity.

LoRa is specifically designed for long-range, low-power communications and provides exceptional receiver sensitivity compared to conventional narrowband radio systems, such as FSK. Although this comes at the cost of reduced throughput, our calculations showed that the available bitrate remains sufficient for heavily compressed voice transmission. This makes LoRa a good compromise between range, reliability and implementation complexity for a digital walkie-talkie.

In short, we deliberately sacrificed audio quality and throughput in exchange for communication range and link robustness.

The `433 MHz` (UHF) band allows for free public usage (LPD band) under specific conditions. In Europe (at least in France), the regulation covers `433.05 MHz` to `434.79 MHz`, split into 69 channels with a `25 kHz` spacing.

> ### Legal Constraints
> The maximum allowed transmission power is `10 mW` with a maximum duty cycle of $\alpha = 0.10\%$ (meaning 6 minutes of cumulative transmission per hour). If you hold the PTT button for a `10 s` message, you must legally wait `90 s` before transmitting again. We plan to implement a software *cooldown mode* to prevent penalties (though we also secretly planned to bake in a *law-bypass mode* for ~~curiosity~~ laboratory testing).

## RF Parameters

To transmit compressed audio frames successfully, we need a balance between range and throughput. Based on Excel simulations of different scenarios, we settled on the following settings:

> [!NOTE]
> <details>
> <summary><strong>Carrier Frequency:</strong> <code>433.050 MHz</code> to <code>434.750 MHz</code> (Configurable via UI)</summary>
> <br>
> The radio frequency used for transmission. All communicating devices must be configured to the same frequency (or channel) to exchange data successfully.
>
> </details>
>
> <details>
> <summary><strong>Spreading Factor (SF):</strong> <code>SF7</code></summary>
> <br>
> Controls the trade-off between throughput and range. A lower SF increases data rate and reduces airtime, while a higher SF improves receiver sensitivity and communication range.
>
> </details>
>
> <details>
> <summary><strong>Bandwidth (BW):</strong> <code>250 kHz</code></summary>
> <br>
> Defines the width of the radio channel. Higher bandwidth increases throughput and reduces transmission time, but generally decreases receiver sensitivity.
>
> </details>
>
> <details>
> <summary><strong>Coding Rate (CR):</strong> <code>4/5</code></summary>
> <br>
> Determines the amount of error correction added to transmitted data. Lower redundancy improves throughput, while higher redundancy increases resistance to interference and packet loss.
>
> </details>

### Tested Configurations

| SF  | BW (kHz) | CR | Theoretical Bitrate (kbit/s) | Expected Range | Comments |
|-----|---|----|---|---|---|
| 7 | 125 | 4/5 | 5.47  | Short | Low range, good robustness margin |
| 7 | 250 | 4/5 | 10.94 | Medium | Best trade-off for voice transmission |
| 8 | 125 | 4/5 | 3.13  | Medium | Balanced configuration |
| 8 | 250 | 4/5 | 6.25  | Medium | Slightly improved throughput |
| 9 | 125 | 4/5 | 1.76  | Long | Good range, limited audio quality |
| 9 | 250 | 4/5 | 3.52  | Long | Stable long-range voice link |
| 10  | 125 | 4/5 | 0.98  | Very long | Marginal for real-time voice |
| 10  | 250 | 4/5 | 1.95  | Long | Only usable with aggressive compression |
| 11  | 125 | 4/5 | 0.54  | Very long | Near limit for intelligible speech |
| 11  | 250 | 4/5 | 1.10  | Very long | Only emergency/low quality voice |
| 12  | 125 | 4/5 | 0.29  | Extreme | Practically unusable for voice |
| 12  | 250 | 4/5 | 0.58  | Extreme | Voice transmission not feasible |

### Throughput Analysis

To validate our radio settings before implementation, we used the theoretical LoRa useful bitrate formula:

$$
R_b = SF \times \frac{BW}{2^{SF}} \times \frac{4}{4 + CR}
$$

Where:

- `SF` is the Spreading Factor
* `BW` is the channel bandwidth in Hz
- `CR` is the Coding Rate parameter (`1` for 4/5, `2` for 4/6, etc.)

Using our selected configuration (`SF7`, `BW = 250 kHz`, `CR = 1`, corresponding to a coding rate of `4/5`), we obtain:

$$
R_b = 7 \times \frac{250000}{2^7} \times \frac{4}{5}
\approx 10.9\ \text{kbit/s}
$$

This theoretical throughput was used during Excel simulations to evaluate whether compressed audio frames could be transmitted fast enough while maintaining acceptable communication range. The actual application-level throughput is slightly lower due to LoRa overhead (preamble, headers, CRC) and our custom protocol headers.

### From Radio Throughput to Voice Transmission

The estimated useful bitrate of approximately `10.9 kbit/s` gives us a theoretical upper bound for real-time audio transmission. Since human speech remains intelligible at relatively low bitrates when compressed efficiently, this throughput is sufficient for a digital walkie-talkie application.

Modern speech codecs such as Opus can produce understandable voice streams at bitrates ranging from roughly `6 kbit/s` to `12 kbit/s`, depending on the desired quality and latency. This makes our selected LoRa configuration viable for transmitting compressed voice while maintaining acceptable communication range.

The audio acquisition, compression strategy and resulting bitrate requirements are discussed in detail in the [audio documentation](./audio.md).

## Custom Protocol
Because LoRa is fundamentally half-duplex (and so are basic walkie-talkies), our system cannot send and receive sound at the same time. Therefore, we managed to implement clean tasks, to properly handle this constraint.

### Frame Format
Every packet contains a minimal overhead header preceding the compressed audio payload:

| Field | Size | Description |
|---|---|---|
| `ADDR_SRC` | 1 byte | Source device identifier (`0x01` to `0xFE`) |
| `ADDR_DST` | 1 byte | Destination device identifier (`0xFF` for broadcast) |
| `FLAGS` | 1 byte | Frame control (Start of transmission, silence, End of frame) |
| `SEQ` | 1 byte | Sequence tracking number to catch dropped packets |
| `PAYLOAD` | Variable | Compressed voice data |

## SX1278 Configuration
The transceiver registers are fine-tuned using the following low-level behaviors:

- **Preamble Length:** Configured to `8 symbols` (default) to provide reliable receiver synchronization.
* **CRC Checking:** Enabled in hardware. Corrupted RF frames are automatically dropped by the transceiver, letting our software insert clean silence frames rather than raw static noise into the audio stream.
- **Explicit Header Mode:** Enabled. Explicit frames carry payload size, coding rate, and CRC indicators natively, ensuring robust decoding.
* **AGC & LNA:** Enabled. The Low Noise Amplifier defaults to maximum gain (`G1` state) and gets managed natively by the chip to prevent up-close saturation.

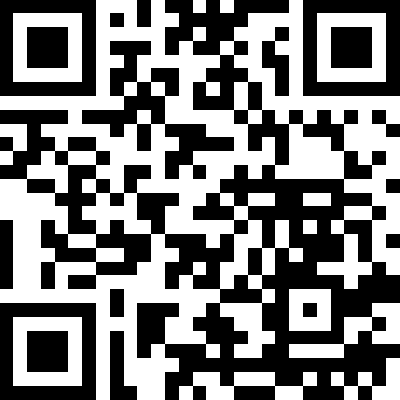
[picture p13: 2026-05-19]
hardware/talk-e/github.png

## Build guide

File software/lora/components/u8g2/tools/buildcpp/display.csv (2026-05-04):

# 1. device name
# 2. pinset
# 3. constructor name w/o prefix
u8x8_d_ssd1306_128x64_noname | 4WSWSPI | SSD1306_128X64_4W_SW_SPI
u8x8_d_ssd1306_128x64_noname | 4WHWSPI | SSD1306_128X64_4W_HW_SPI
u8x8_d_ssd1306_128x64_noname | 3WSWSPI | SSD1306_128X64_3W_SW_SPI
u8x8_d_ssd1306_128x64_noname | SSDSWI2C | SSD1306_128X64_SW_I2C
u8x8_d_ssd1306_128x64_noname | 6800 | SSD1306_128X64_6800
u8x8_d_ssd1306_128x64_noname | 8080 | SSD1306_128X64_8080

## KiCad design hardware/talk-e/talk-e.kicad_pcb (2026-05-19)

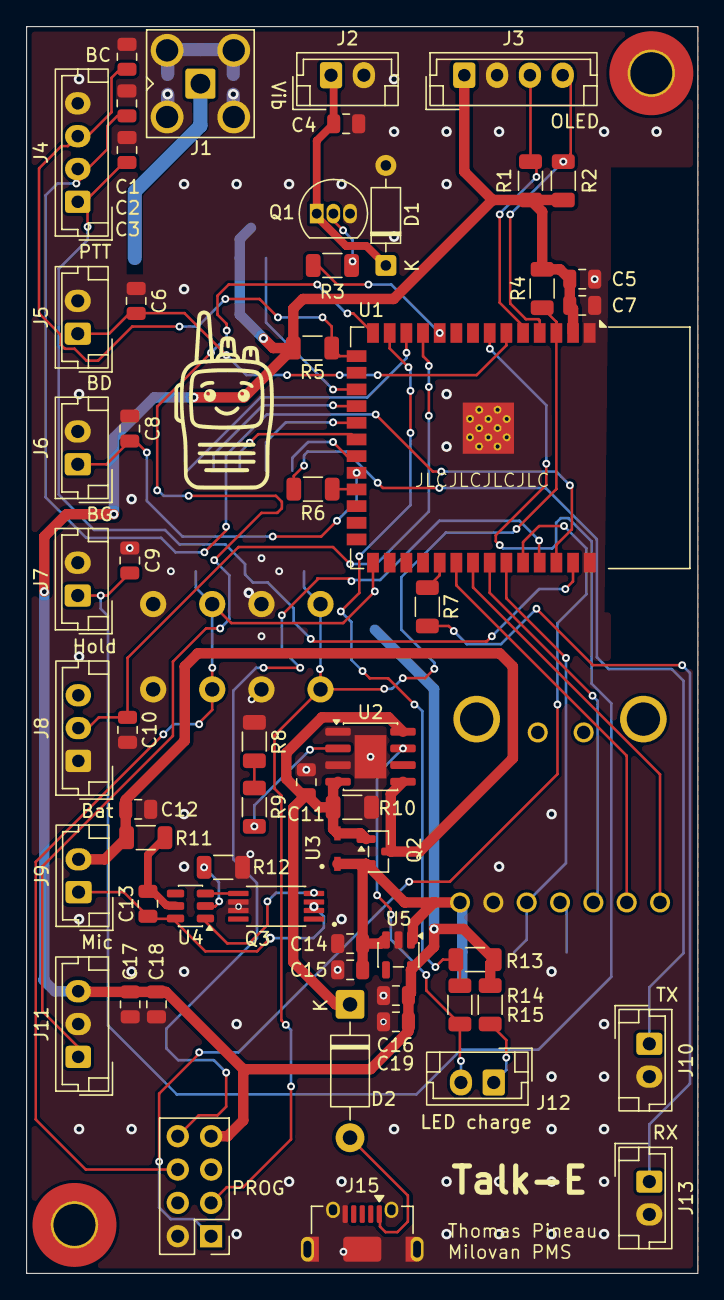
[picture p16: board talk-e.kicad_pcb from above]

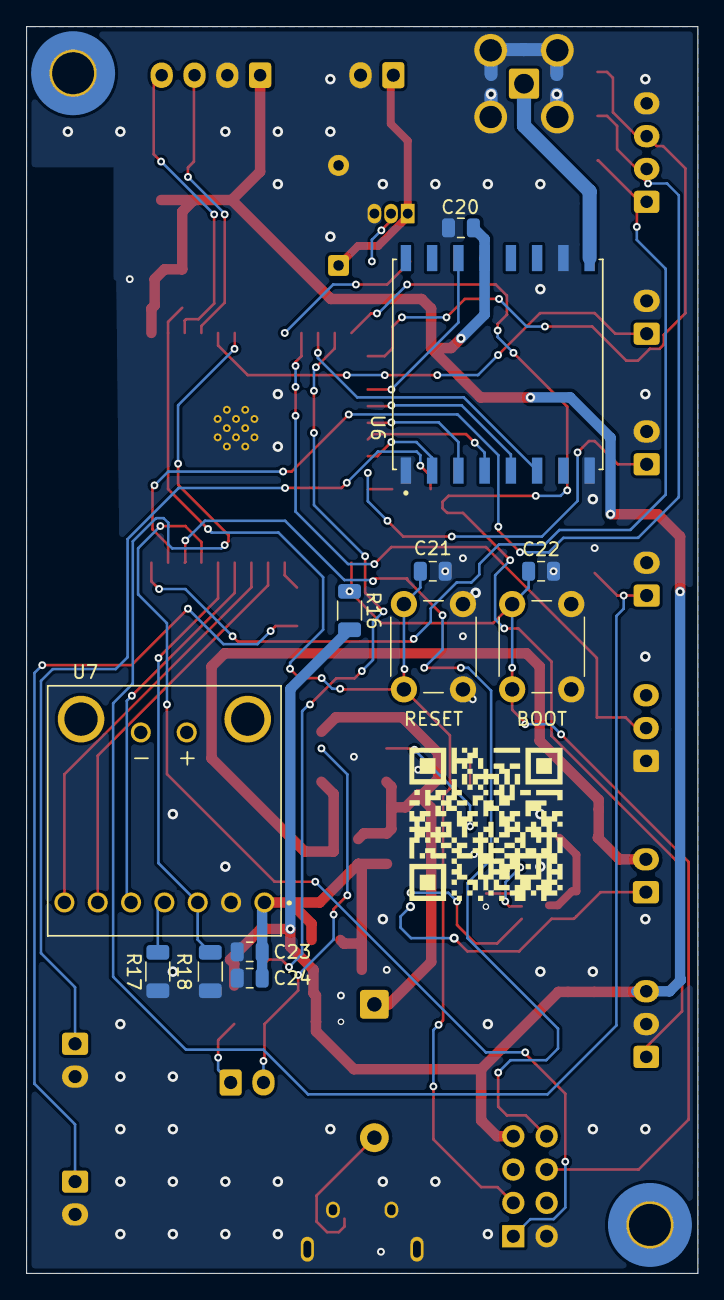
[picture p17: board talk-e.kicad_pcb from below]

Board: 2 copper layers, 51.1 x 95.0 mm, 71 parts (12 on the bottom side), 49 nets.

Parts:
BOOT: SW_Push; SW_PUSH_6mm
C1, C2, C3, C6, C7, C8, C9, C10, C11, C13, C15, C18, C19, C20, C21, C22, C24: 100n; C_0805_2012Metric
C4: 100µ; C_0805_2012Metric
C5, C12, C14, C16, C17: 10µ; C_0805_2012Metric
C23: 47µ; C_0805_2012Metric
D1: 1N4148; D_DO-35_SOD27_P7.62mm_Horizontal
D2: 1N5819; D_DO-41_SOD81_P10.16mm_Horizontal
J1: Conn_Coaxial; SMA_Amphenol_901-143_Horizontal
J2, J5, J6, J7, J10, J12, J13: Conn_01x02_Socket; JST_EH_B2B-EH-A_1x02_P2.50mm_Vertical
J3, J4: Conn_01x04_Socket; JST_EH_B4B-EH-A_1x04_P2.50mm_Vertical
J8, J11: Conn_01x03_Socket; JST_EH_B3B-EH-A_1x03_P2.50mm_Vertical
J9: Conn_01x02; JST_EH_B2B-EH-A_1x02_P2.50mm_Vertical
J15: USB_B_Micro; USB_Micro-AB_Molex_47590-0001
PROG: Conn_02x04_Odd_Even; PinHeader_2x04_P2.54mm_Vertical
Q1: BC337; TO-92_Inline
Q2: IRLML6402; SOT-23
Q3: FS8205A; SOP65P640X120-8N
R1, R2: 4.7k; R_1206_3216Metric
R3, R8, R9, R12: 1k; R_1206_3216Metric
R4, R5, R13, R16: 10k; R_1206_3216Metric
R6, R7, R15: 330R; R_1206_3216Metric
R10, R17, R18: 100k; R_1206_3216Metric
R11: 100R; R_1206_3216Metric
R14: 47k; R_1206_3216Metric
RESET: SW_Push; SW_PUSH_6mm
U1: ESP32-S3-WROOM-1
U2: TP4056-42-ESOP8; SOIC-8-1EP_3.9x4.9mm_P1.27mm_EP2.41x3.3mm
U3: SBR130S3-7
U4: DW01A; SOT-23-6
U5: AP2112K-3.3; SOT-23-5
U6: RFM96W-433S2; MODULE_RFM96W-433S2
U7: 3006; MODULE_3006

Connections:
+3.3V: C5.1, C7.1, C16.1, C17.1, C18.1, C19.1, C20.1, J3.1, J11.3, PROG.7, R1.2, R2.2, R4.2, R5.2, R13.1, R15.1, R16.2, U1.2 (3V3), U5.5 (VOUT), U6.13 (3.3V)
+5V: C11.1, D2.1 (K), Q2.1 (G), R10.2, U2.4 (V_{CC}), U2.8 (CE), U3.A
/ADC_MICRO: J11.1, U1.14 (USB_D+)
/B+: C12.1, J9.2, Q2.3 (D), R11.1, U2.5 (BAT)
/B-: C13.2, J9.1, Q3.2, Q3.3, U4.6 (GND)
/BTN_1: C9.1, J7.1, U1.7 (IO7)
/BTN_2: C8.1, J6.1, U1.22 (IO14)
/BTN_PTT: C6.1, J5.1, U1.6 (IO6)
/CHRG: J12.2, R14.1, U2.7 (~CHRG)
/ENC_A: C3.1, J4.1, U1.39 (IO1)
/ENC_B: C2.1, J4.2, U1.38 (IO2)
/ENC_SW: C1.1, J4.3, R5.1, U1.15 (IO3)
/GPIO_RX: R6.1, U1.23 (IO21)
/GPIO_TX: R7.1, U1.31 (IO38)
/I2C_SCL: J3.3, R1.1, U1.5 (IO5)
/I2C_SDA: J3.4, R2.1, U1.4 (IO4)
/I2S_BCLK: U1.32 (IO39), U7.JP1_6 (BCLK)
/I2S_DOUT: U1.34 (IO41), U7.JP1_5 (DIN)
/I2S_LRCLK: U1.33 (IO40), U7.JP1_7 (LRCLK)
/I2S_SD: R18.1, U1.35 (IO42), U7.JP1_3 (SD)
/J_VIB_+: C4.1, D1.1 (K), J2.1, Q1.1 (C)
/LORA_CS: U1.18 (IO10), U6.5 (NSS)
/LORA_DIO0: U1.17 (IO9), U6.14 (DIO0)
/LORA_MISO: U1.21 (IO13), U6.2 (MISO)
/LORA_MOSI: U1.19 (IO11), U6.3 (MOSI)
/LORA_RST: U1.12 (IO8), U6.6 (RESET)
/LORA_SCK: U1.20 (IO12), U6.4 (SCK)
/VBUS: D2.2 (A), J15.1 (VBUS)
/VIBREUR: R3.1, U1.10 (IO17)
ANTENNA: J1.1 (In), U6.9 (ANT)
GND: BOOT.2, C1.2, C2.2, C3.2, C4.2, C5.2, C6.2, C7.2, C8.2, C9.2, C10.2, C11.2, C12.2, C14.2, C15.2, C16.2, C17.2, C18.2, C19.2, C20.2, C21.2, C22.2, C23.2, C24.2, D1.2 (A), J1.2 (Ext), J2.2, J3.2, J4.4, J5.2, J6.2, J7.2, J8.1, J10.2, J11.2, J13.2, J15.5 (GND), J15.SH (Shield), PROG.2, Q1.3 (E), Q3.6, Q3.7, R8.2, R10.1, R12.1, R17.1, R18.2, RESET.2, U1.1 (GND), U1.40 (GND), U1.41 (GND), U2.1 (TEMP), U2.3 (GND), U2.9 (EPAD), U5.2 (GND), U6.1 (GND), U6.8 (GND), U6.10 (GND), U7.JP1_2 (GND)
GPIO0: BOOT.1, C22.1, PROG.6, R16.1, U1.27 (IO0)
GPIO_CHRG: R13.2, R14.2, U1.13 (USB_D-)
unnamed: J10.1, R6.2
unnamed: J12.1, R15.2
unnamed: J13.1, R7.2
unnamed: Q1.2 (B), R3.2
unnamed: R8.1, R9.2
unnamed: R9.1, U2.2 (PROG)
unnamed: R12.2, U4.2 (CS)
unnamed: Q3.5, U4.3 (OC)
unnamed: Q3.4, U4.1 (OD)
unnamed: C13.1, R11.2, U4.5 (VCC)
unnamed: R17.2, U7.JP1_4 (GAIN)
OUT+: C14.1, C15.1, C23.1, C24.1, Q2.2 (S), U3.C, U5.1 (VIN), U5.3 (EN), U7.JP1_1 (VDD)
RESET: C21.1, PROG.3, R4.1, RESET.1, U1.3 (EN)
RXD: PROG.8, U1.37 (TXD0)
SW_LOCK: C10.1, J8.2, U1.11 (IO18)
TXD: PROG.1, U1.36 (RXD0)

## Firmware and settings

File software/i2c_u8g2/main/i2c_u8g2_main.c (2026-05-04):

/*
 * SPDX-FileCopyrightText: 2025 Espressif Systems (Shanghai) CO LTD
 *
 * SPDX-License-Identifier: Unlicense OR CC0-1.0
 */

/**
 * @file i2c_u8g2_main.c
 * @brief I2C U8G2 Display Demo using ESP-IDF I2C Master Driver
 *
 * This example demonstrates how to use the U8G2 graphics library with
 * SSD1306 display over I2C interface using the new ESP-IDF I2C master driver.
 *
 * The demo showcases various U8G2 features including text display, geometric shapes,
 * pixel manipulation, progress bars, animations, and bitmap display.
 */

#include <stdio.h>
#include "freertos/FreeRTOS.h"
#include "freertos/task.h"
#include "driver/i2c_master.h"
#include "driver/gpio.h"
#include "esp_log.h"
#include "esp_check.h"
#include "sdkconfig.h"
#include "u8g2.h"
#include "u8g2_demo.h"

static const char *TAG = "U8G2";

/* I2C Configuration (configurable via menuconfig) */
#define I2C_MASTER_NUM    I2C_NUM_0                        /*!< I2C master port number */
#define I2C_MASTER_SDA_IO CONFIG_I2C_MASTER_SDA            /*!< GPIO number used for I2C master data  */
#define I2C_MASTER_SCL_IO CONFIG_I2C_MASTER_SCL            /*!< GPIO number used for I2C master clock */
#define I2C_FREQ_HZ       CONFIG_I2C_MASTER_FREQUENCY      /*!< I2C master clock frequency */
#define I2C_TIMEOUT_MS    1000                             /*!< I2C master timeout */

/* Display Configuration (configurable via menuconfig) */
#define I2C_DISPLAY_ADDRESS  CONFIG_I2C_DISPLAY_ADDRESS    /*!< Display I2C address */

static i2c_master_bus_handle_t i2c_bus_handle = NULL;   /*!< I2C master bus handle */
static i2c_master_dev_handle_t display_dev_handle = NULL;  /*!< Display device handle */

/**
 * @brief U8X8 I2C communication callback function
 *
 * This function handles all I2C communication between U8G2 library and display controller.
 * Please refer to https://github.com/olikraus/u8g2/wiki/Porting-to-new-MCU-platform for more details.
 *
 * @param[in] u8x8 Pointer to u8x8 structure (not used)
 * @param[in] msg Message type from U8G2 library
 * @param[in] arg_int Integer argument (varies by message type)
 * @param[in] arg_ptr Pointer argument (varies by message type)
 *
 * @return
 *     - 1: Success
 *     - 0: Failure
 */
static uint8_t u8x8_byte_i2c_cb(u8x8_t *u8x8, uint8_t msg,
                                uint8_t arg_int, void *arg_ptr)
{
    static uint8_t buffer[132];  /*!< Enhanced buffer: control byte + 128 data bytes + margin */
    static uint8_t buf_idx;      /*!< Current buffer index */

    switch (msg) {
    case U8X8_MSG_BYTE_INIT:
        /* Add display device to the I2C bus */
        i2c_device_config_t dev_config = {
            .dev_addr_length = I2C_ADDR_BIT_LEN_7,
            .device_address = I2C_DISPLAY_ADDRESS,
            .scl_speed_hz = I2C_FREQ_HZ,
            .scl_wait_us = 0,  /* Use default value */
            .flags.disable_ack_check = false,
        };

        esp_err_t ret = i2c_master_bus_add_device(i2c_bus_handle, &dev_config, &display_dev_handle);
        if (ret != ESP_OK) {
            ESP_LOGE(TAG, "I2C master driver initialized failed");
            return 0;
        }

        ESP_LOGI(TAG, "I2C master driver initialized successfully");
        break;

    case U8X8_MSG_BYTE_START_TRANSFER:
        /* Start transfer, reset buffer */
        buf_idx = 0;
        break;

    case U8X8_MSG_BYTE_SET_DC:
        /* DC (Data/Command) control - handled by SSD1306 protocol */
        break;

    case U8X8_MSG_BYTE_SEND:
        /* Add data bytes to buffer */
        for (size_t i = 0; i < arg_int; ++i) {
            buffer[buf_idx++] = *((uint8_t*)arg_ptr + i);
        }
        break;

    case U8X8_MSG_BYTE_END_TRANSFER:
        /* Transmit data using new I2C driver */
        if (buf_idx > 0 && display_dev_handle != NULL) {
            esp_err_t ret = i2c_master_transmit(display_dev_handle, buffer, buf_idx, I2C_TIMEOUT_MS);
            if (ret != ESP_OK) {
                ESP_LOGE(TAG, "I2C master transmission failed");
                return 0;
            }

            /* Debug output: show transmitted data */
            ESP_LOGD(TAG, "Sent %d bytes to 0x%02X: control_byte=0x%02X",
                     buf_idx, I2C_DISPLAY_ADDRESS, buffer[0]);
        }
        break;

    default:
        return 0;
    }
    return 1;
}

/**
 * @brief U8X8 GPIO control and delay callback function for ESP32
 *
 * This function handles GPIO operations and timing delays required by U8G2 library.
 * Please refer to https://github.com/olikraus/u8g2/wiki/Porting-to-new-MCU-platform for more details.
 *
 * @param[in] u8x8 Pointer to u8x8 structure (not used)
 * @param[in] msg Message type from U8G2 library
 * @param[in] arg_int Integer argument (varies by message type)
 * @param[in] arg_ptr Pointer argument (not used)
 *
 * @return
 *     - 1: Success
 *     - 0: Failure
 */
static uint8_t u8x8_gpio_delay_cb(u8x8_t *u8x8, uint8_t msg,
                                  uint8_t arg_int, void *arg_ptr)
{
    switch (msg) {
    case U8X8_MSG_GPIO_AND_DELAY_INIT:
        ESP_LOGI(TAG, "GPIO and delay initialization completed");
        break;

    case U8X8_MSG_DELAY_MILLI:
        /* Millisecond delay */
        vTaskDelay(pdMS_TO_TICKS(arg_int));
        break;

    case U8X8_MSG_DELAY_10MICRO:
        /* 10 microsecond delay */
        esp_rom_delay_us(arg_int * 10);
        break;

    case U8X8_MSG_DELAY_100NANO:
        /* 100 nanosecond delay - use minimal delay on ESP32 */
        __asm__ __volatile__("nop");
        break;

    case U8X8_MSG_DELAY_I2C:
        /* I2C timing delay: 5us for 100KHz, 1.25us for 400KHz */
        esp_rom_delay_us(5 / arg_int);
        break;

    case U8X8_MSG_GPIO_RESET:
        /* GPIO reset control (optional for most display controllers) */
        break;

    default:
        /* Other GPIO messages not handled */
        return 0;
    }
    return 1;
}

/**
 * @brief Display the current demo cycle number on the display screen.
 *
 * @param u8g2 Pointer to the U8G2 display structure.
 * @param demo_cycle The current demo cycle number to display.
 */
static void show_demo_cycle(u8g2_t* u8g2, int demo_cycle)
{
    u8g2_ClearBuffer(u8g2);
    u8g2_SetFont(u8g2, u8g2_font_ncenB08_tr);
    u8g2_DrawStr(u8g2, 25, 25, "Demo Cycle");
    u8g2_SetFont(u8g2, u8g2_font_ncenB14_tr);
    char cycle_str[16];
    snprintf(cycle_str, sizeof(cycle_str), "%d", demo_cycle);
    u8g2_DrawStr(u8g2, 55, 45, cycle_str);
    u8g2_SendBuffer(u8g2);
    vTaskDelay(pdMS_TO_TICKS(2000));    /* delay for showing static display */
}

/**
 * @brief Main application entry point
 *
 * This function initializes the U8G2 library, configures the display controller,
 * and runs a continuous demo loop showcasing various U8G2 features.
 *
 * The demo includes:
 * - Text display with different fonts
 * - Geometric shapes (rectangles, circles, triangles, lines)
 * - Pixel manipulation
 * - Animated progress bar
 * - Bouncing ball animation
 * - Bitmap display
 */
void app_main(void)
{
    u8g2_t u8g2;

    ESP_LOGI(TAG, "Starting U8G2 display demo program (menuconfig based configuration)");
    ESP_LOGI(TAG, "I2C Configuration: SDA=GPIO%d, SCL=GPIO%d, Freq=%dHz, Timeout=%dms",
             I2C_MASTER_SDA_IO, I2C_MASTER_SCL_IO, I2C_FREQ_HZ, I2C_TIMEOUT_MS);
    ESP_LOGI(TAG, "Display Configuration: Address=0x%02X",
             I2C_DISPLAY_ADDRESS);

    i2c_master_bus_config_t bus_config = {
        .i2c_port = I2C_MASTER_NUM,
        .sda_io_num = I2C_MASTER_SDA_IO,
        .scl_io_num = I2C_MASTER_SCL_IO,
        .clk_source = I2C_CLK_SRC_DEFAULT,
        .glitch_ignore_cnt = 7,
        .intr_priority = 0,
        .trans_queue_depth = 0,  /* 0 = synchronous mode */
        .flags.enable_internal_pullup = true,
    };

    /* Create I2C master bus */
    ESP_ERROR_CHECK(i2c_new_master_bus(&bus_config, &i2c_bus_handle));

    /*
     * Initialize U8G2 for your display type.
     * Change the u8g2_Setup_xxx function below to match your display controller,
     * e.g. SSD1306, SH1106, SSD1327, etc.
     * See: https://github.com/olikraus/u8g2/wiki/u8g2setupc
     */
    u8g2_Setup_sh1106_i2c_128x64_noname_f(
        &u8g2, U8G2_R0,
        u8x8_byte_i2c_cb,   /* I2C communication callback */
        u8x8_gpio_delay_cb  /* GPIO and delay callback */
    );

    /* Initialize display hardware */
    ESP_LOGI(TAG, "Initializing display...");
    u8g2_InitDisplay(&u8g2);
    ESP_LOGI(TAG, "Setting power mode...");
    u8g2_SetPowerSave(&u8g2, 0);  /* Wake up display */
    ESP_LOGI(TAG, "Display initialization completed");

    /* Main demo loop - runs continuously */
    int demo_cycle = 0;
    while (1) {
        ESP_LOGI(TAG, "Demo cycle: %d", ++demo_cycle);

        /* Execute demo sequence */
        demo_text_display(&u8g2);
        demo_shapes(&u8g2);
        demo_pixels(&u8g2);
        demo_progress_bar(&u8g2);
        demo_animation(&u8g2);
        demo_bitmap(&u8g2);
        show_demo_cycle(&u8g2, demo_cycle);
    }
}

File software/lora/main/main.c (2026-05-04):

/*
 *
 */

#include <stdio.h>
#include <string.h>
#include "sdkconfig.h"
#include "cmd_i2ctools.h"
#include "freertos/FreeRTOS.h"
#include "freertos/task.h"
#include "lora.h"


#include "driver/i2c_master.h"
#include "driver/gpio.h"
#include "esp_log.h"
#include "esp_check.h"
#include "u8g2.h"

// @note Configuration avec idf.py menuconfig
// TTGO T-Beam V1.1 : CS GPIO 18, RST GPIO 23, SCK GPIO 5, MISO GPIO 19, MOSI GPIO 27

#define TRANSCIVER_MODE 0 // 0: Mode RX, 1: Mode TX

uint8_t buf[32]; // Buffer pour les données reçues

extern void display_task(void *pvParameters);

void task_tx(void *p)
{
    for (;;)
    {
        vTaskDelay(pdMS_TO_TICKS(5000));
        lora_send_packet((uint8_t *)"Hello", 5);
        printf("packet sent...\n");
    }
}

void task_rx(void *p)
{
    int x;
    for (;;)
    {
        lora_receive();
        while (lora_received())
        {
            x = lora_receive_packet(buf, sizeof(buf));
            buf[x] = 0;
            printf("Received: %s\n", buf);
            lora_receive();
        }
        vTaskDelay(1);
    }
}

void app_main(void)
{
    lora_init();

    // Paramètres de configuration du module LoRa
    lora_explicit_header_mode();  // En-tête explicite : les paquets contiennent un en-tête avec des informations sur la taille et le type de données
    lora_set_tx_power(10);        // Puissance d'émission (dBm)
    lora_set_frequency(433e6);    // Fréquence (433 MHz)
    lora_set_spreading_factor(7); // Facteur de propagation (SF7)
    lora_set_bandwidth(250e3);    // Bande passante (250 kHz)
    lora_set_coding_rate(5);      // Taux de codage (4/x)
    lora_enable_crc();            // CRC activé (Cyclic Redundancy Check) : le récepteur rejette silencieusement les trames corrompues

    if (TRANSCIVER_MODE == 0)
    { // Mode émetteur
        // Tâche FreeRTOS qui s'exécutera en parallèle du reste du programme
        xTaskCreate(
            &task_tx,  // Pointeur vers la fonction de la tâche à exécuter
            "task_tx", // Nom de la tâche
            2048,      // Taille de la pile allouée à cette tâche (octets)
            NULL,      // Paramètre à passer à la tâche
            5,         // Priorité de la tâche (plus le nombre est élevé, plus la tâche est prioritaire)
            NULL       // Pointeur pour récupérer le handle de la tâche
        );

        // Tâche pour afficher les données sur l'écran OLED
        xTaskCreate(&display_task, "display_task", 4096, NULL, 4, NULL);
    }
    else
    { // Mode récepteur
        xTaskCreate(&task_rx, "task_rx", 2048, NULL, 5, NULL);
    }
}

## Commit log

2026-05-04 Projects creation
    [talk-e.kicad_pcb, talk-e.kicad_sch]
2026-05-04 Add u8g2 library and test program oled.c
    Took library from i2c_u8g2 example ESP-IDF project
    [display.csv, hx1230_commands.ods]
2026-05-07 Progress on battery charging schematic
    TP4056 + DW01A + FS8205A
    [talk-e.kicad_sch]
2026-05-08 Added SX1278 connections to ESP32-S3 in schematic
    [talk-e.kicad_sch]
2026-05-09 Added SH1106 OLED screen to schematic
    [talk-e.kicad_sch]
2026-05-09 Added EC12 incremental encoder to schematic
    [talk-e.kicad_sch]
2026-05-09 Added 3 buttons and power switch
    [ihm.kicad_sch, talk-e.kicad_sch]
2026-05-09 Added vibration motor to schematic
    [ihm.kicad_sch]
2026-05-09 Added RESET button and TX/RX LEDs to schematic
    [ihm.kicad_sch]
2026-05-09 Added RESET button and TX/RX LEDs to schematic (2)
    [ihm.kicad_sch]
2026-05-10 Added TP4056, DW01A, AP2112K-3.3 to schematic
    [ihm.kicad_sch, talk-e.kicad_sch]
2026-05-10 Added UART IDC connector, ESP32 decoupling capacitors
    [ihm.kicad_sch, talk-e.kicad_sch]
2026-05-10 Added SMA connector (antenna)
    [ihm.kicad_sch]
2026-05-10 Added crystal
    [ihm.kicad_sch]
2026-05-10 Something moved in the schematic but idk what
    [ihm.kicad_sch, talk-e.kicad_sch]
2026-05-11 add audio components
    add audio components
    [talk-e.kicad_sch]
2026-05-12 Added ampli + mic + finished GPIO mapping
    [ihm.kicad_sch, talk-e.kicad_sch]
2026-05-12 Replaced ESP32-S3 with ESP32-S3-WROOM-1
    [ihm.kicad_sch]
2026-05-19 Finished routing + PCB ready for production
    [ihm.kicad_sch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]
2026-06-25 Add case README.md
